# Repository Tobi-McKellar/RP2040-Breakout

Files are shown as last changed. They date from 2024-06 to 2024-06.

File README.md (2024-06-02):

# RP2040-Breakout
A simple RP2040 breakout.





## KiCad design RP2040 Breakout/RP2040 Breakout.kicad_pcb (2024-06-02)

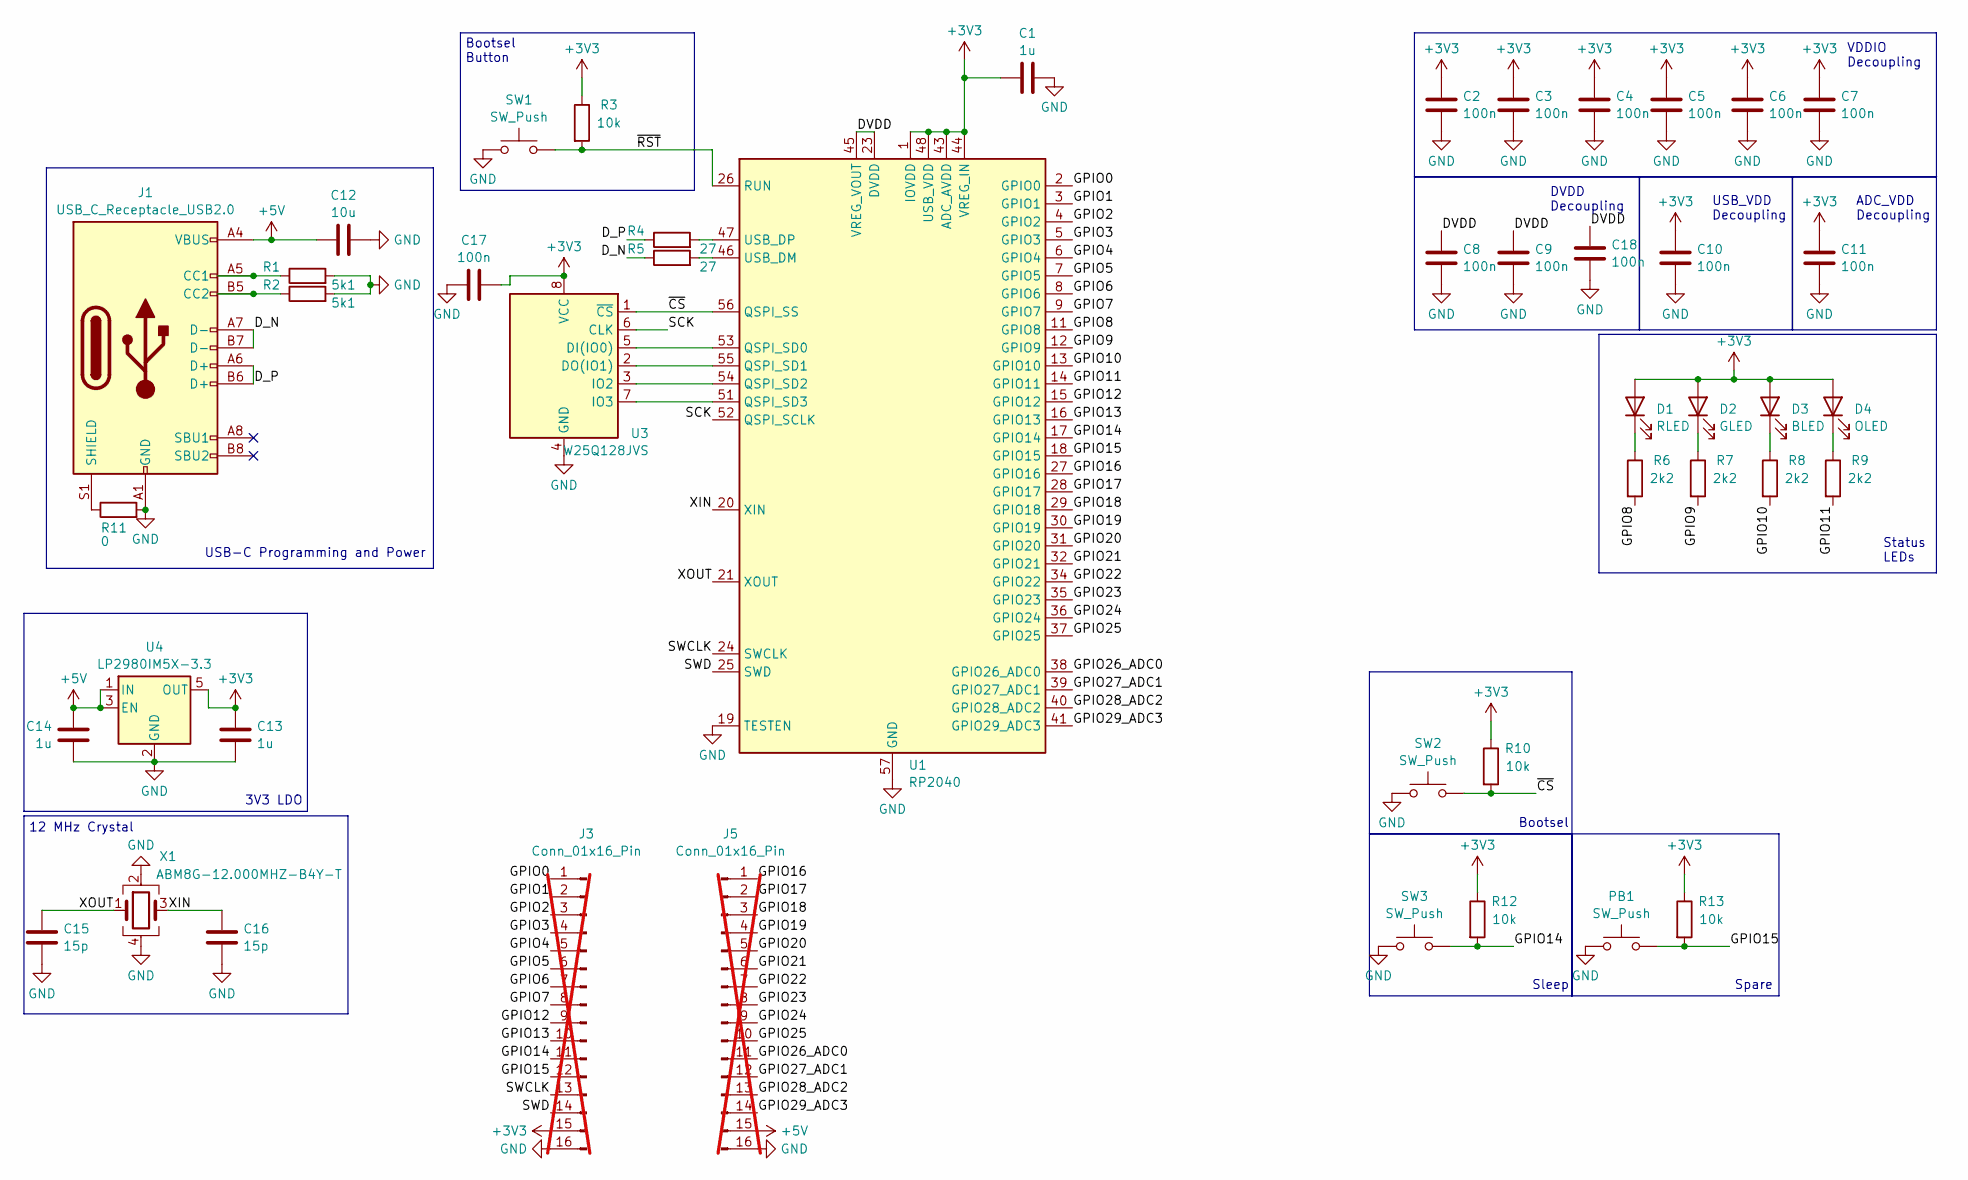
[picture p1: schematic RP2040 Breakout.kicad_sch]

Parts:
C1, C13, C14: 1u; C_0402_1005Metric; JLC Part Number C528974
C2, C3, C4, C5, C6, C7, C8, C9, C10, C11, C17, C18: 100n; C_0402_1005Metric; JLC Part Number C60474
C12: 10u; C_0603_1608Metric; JLC Part Number C2959727
C15, C16: 15p; C_0402_1005Metric; JLC Part Number C106997
D1: RLED; D_0402_1005Metric; JLC Part Number C264407
D2: GLED; D_0402_1005Metric; JLC Part Number C264408
D3: BLED; D_0402_1005Metric; JLC Part Number C131223
D4: OLED; D_0402_1005Metric; JLC Part Number C88330
J1: USB_C_Receptacle_USB2.0; USB_C_Receptacle_GCT_USB4105-xx-A_16P_TopMnt_Horizontal; JLC Part Number C2848971
J3, J5: Conn_01x16_Pin; PinHeader_1x16_P2.54mm_Vertical; not fitted
PB1: SW_Push; SW_SPST_PTS810; JLC Part Number C2888430
R1, R2: 5k1; R_0402_1005Metric; JLC Part Number C25905
R3, R10, R12, R13: 10k; R_0402_1005Metric; JLC Part Number C25744
R4, R5: 27; R_0402_1005Metric; JLC Part Number C25885
R6, R7, R8, R9: 2k2; R_0402_1005Metric; JLC Part Number C25879
R11: 0; R_0402_1005Metric; JLC Part Number C25885
SW1, SW2, SW3: SW_Push; SW_SPST_PTS810; JLC Part Number C2888430
U1: RP2040; QFN-56-1EP_7x7mm_P0.4mm_EP3.2x3.2mm; JLC Part Number C2040
U3: W25Q128JVS; SOIC-8_5.23x5.23mm_P1.27mm; JLC Part Number C97521
U4: LP2980IM5X-3.3; SOT-23-5; JLC Part Number C5380654
X1: ABM8G-12.000MHZ-B4Y-T; Oscillator_SMD_Abracon_ASE-4Pin_3.2x2.5mm; JLC Part Number C276421

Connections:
+3V3: C1.1, C2.2, C3.2, C4.2, C5.2, C6.2, C7.2, C10.2, C11.2, C13.2, C17.1, D1.2 (A), D2.2 (A), D3.2 (A), D4.2 (A), J3.15, R3.1, R10.1, R12.1, R13.1, U1.1 (IOVDD), U1.10 (IOVDD), U1.22 (IOVDD), U1.33 (IOVDD), U1.42 (IOVDD), U1.43 (ADC_AVDD), U1.44 (VREG_IN), U1.48 (USB_VDD), U1.49 (IOVDD), U3.8 (VCC), U4.5 (OUT)
+5V: C12.1, C14.2, J1.A4 (VBUS), J1.A9 (VBUS), J1.B4 (VBUS), J1.B9 (VBUS), J5.15, U4.1 (IN), U4.3 (EN)
/DVDD: C8.2, C9.2, C18.2, U1.23 (DVDD), U1.45 (VREG_VOUT), U1.50 (DVDD)
/D_N: J1.A7 (D-), J1.B7 (D-), R5.1
/D_P: J1.A6 (D+), J1.B6 (D+), R4.1
/GPIO0: J3.1, U1.2 (GPIO0)
/GPIO1: J3.2, U1.3 (GPIO1)
/GPIO2: J3.3, U1.4 (GPIO2)
/GPIO3: J3.4, U1.5 (GPIO3)
/GPIO4: J3.5, U1.6 (GPIO4)
/GPIO5: J3.6, U1.7 (GPIO5)
/GPIO6: J3.7, U1.8 (GPIO6)
/GPIO7: J3.8, U1.9 (GPIO7)
/GPIO8: R6.2, U1.11 (GPIO8)
/GPIO9: R7.2, U1.12 (GPIO9)
/GPIO10: R8.2, U1.13 (GPIO10)
/GPIO11: R9.2, U1.14 (GPIO11)
/GPIO12: J3.9, U1.15 (GPIO12)
/GPIO13: J3.10, U1.16 (GPIO13)
/GPIO14: J3.11, R12.2, SW3.2, U1.17 (GPIO14)
/GPIO15: J3.12, PB1.2, R13.2, U1.18 (GPIO15)
/GPIO16: J5.1, U1.27 (GPIO16)
/GPIO17: J5.2, U1.28 (GPIO17)
/GPIO18: J5.3, U1.29 (GPIO18)
/GPIO19: J5.4, U1.30 (GPIO19)
/GPIO20: J5.5, U1.31 (GPIO20)
/GPIO21: J5.6, U1.32 (GPIO21)
/GPIO22: J5.7, U1.34 (GPIO22)
/GPIO23: J5.8, U1.35 (GPIO23)
/GPIO24: J5.9, U1.36 (GPIO24)
/GPIO25: J5.10, U1.37 (GPIO25)
/GPIO26_ADC0: J5.11, U1.38 (GPIO26_ADC0)
/GPIO27_ADC1: J5.12, U1.39 (GPIO27_ADC1)
/GPIO28_ADC2: J5.13, U1.40 (GPIO28_ADC2)
/GPIO29_ADC3: J5.14, U1.41 (GPIO29_ADC3)
/SCK: U1.52 (QSPI_SCLK), U3.6 (CLK)
/SWCLK: J3.13, U1.24 (SWCLK)
/SWD: J3.14, U1.25 (SWD)
/XIN: C16.2, U1.20 (XIN), X1.3
/XOUT: C15.2, U1.21 (XOUT), X1.1
/~CS: R10.2, SW2.2, U1.56 (QSPI_SS), U3.1 (~CS)
/~RST: R3.2, SW1.2, U1.26 (RUN)
GND: C1.2, C2.1, C3.1, C4.1, C5.1, C6.1, C7.1, C8.1, C9.1, C10.1, C11.1, C12.2, C13.1, C14.1, C15.1, C16.1, C17.2, C18.1, J1.A1 (GND), J1.A12 (GND), J1.B1 (GND), J1.B12 (GND), J3.16, J5.16, PB1.1, R1.2, R2.2, R11.2, SW1.1, SW2.1, SW3.1, U1.19 (TESTEN), U1.57 (GND), U3.4 (GND), U4.2 (GND), X1.2, X1.4
unnamed: D1.1 (K), R6.1
unnamed: D2.1 (K), R7.1
unnamed: D3.1 (K), R8.1
unnamed: D4.1 (K), R9.1
unnamed: J1.A5 (CC1), R1.1
unnamed: J1.B5 (CC2), R2.1
unnamed: J1.S1 (SHIELD), R11.1
unnamed: U1.53 (QSPI_SD0), U3.5 (DI(IO0))
unnamed: U1.55 (QSPI_SD1), U3.2 (DO(IO1))
unnamed: U1.54 (QSPI_SD2), U3.3 (IO2)
unnamed: U1.51 (QSPI_SD3), U3.7 (IO3)
unnamed: R5.2, U1.46 (USB_DM)
unnamed: R4.2, U1.47 (USB_DP)

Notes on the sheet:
3V3 LDO
VDDIO Decoupling
12 MHz Crystal
Bootsel
Spare
USB-C Programming and Power
Bootsel Button
USB_VDD Decoupling
Status LEDs
Sleep
DVDD Decoupling
ADC_VDD Decoupling

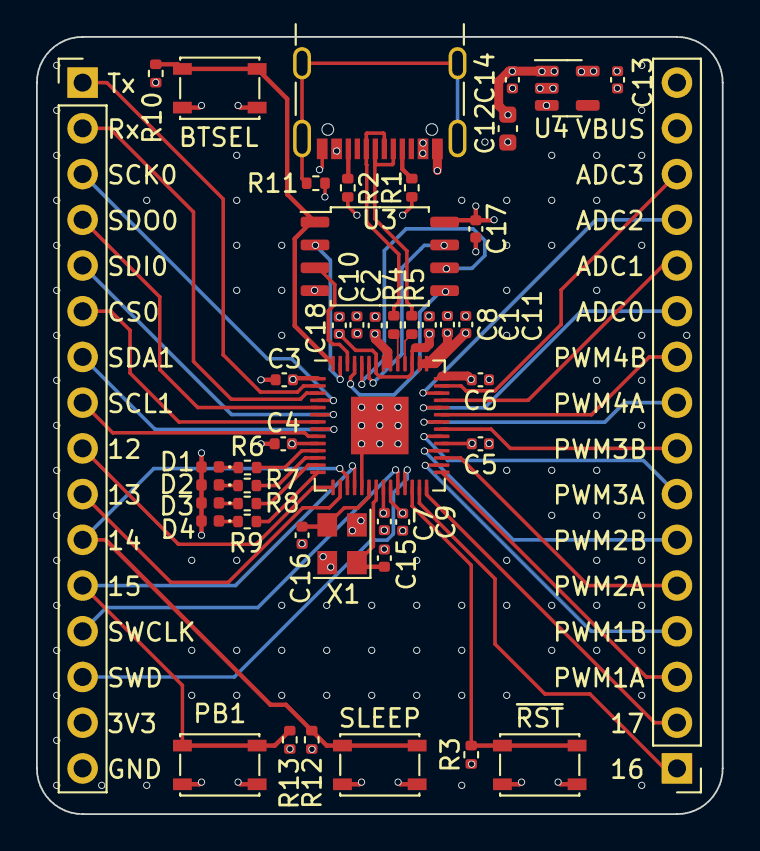
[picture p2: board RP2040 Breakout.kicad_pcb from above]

Board: 6 copper layers, 38.1 x 43.2 mm, 47 parts (1 on the bottom side), 56 nets.

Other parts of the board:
QR*****: QRCODE_httpsgithub.comTobiMcKellarRP2040Breakout

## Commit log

2024-06-02 Add kicad files.
    [RP2040 Breakout.kicad_pcb, RP2040 Breakout.kicad_sch]
2024-06-02 Add PCB image to readme.
2024-06-02 Cleaned up schematic a bit and rerouted buttons.
    [RP2040 Breakout.kicad_pcb, RP2040 Breakout.kicad_sch]
2024-06-02 Add title block to schematic.
    [RP2040 Breakout.kicad_sch]
2024-06-02 Add QR code to github page.
    [RP2040 Breakout.kicad_pcb]
